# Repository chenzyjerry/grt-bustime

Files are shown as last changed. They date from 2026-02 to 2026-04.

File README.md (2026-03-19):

# grt-bustime

Fetch the next two Grand River Transit (GRT) bus arrival times at a stop using a Raspberry Pi and show the arrival time for the two selected bus routes on 7 segment displays.

This project is not affiliated in any way with Grand River Transit. I just like transit.

Interested in doing this yourself? Read the instructions in ```./docs/Instructions.md```.

## Photos

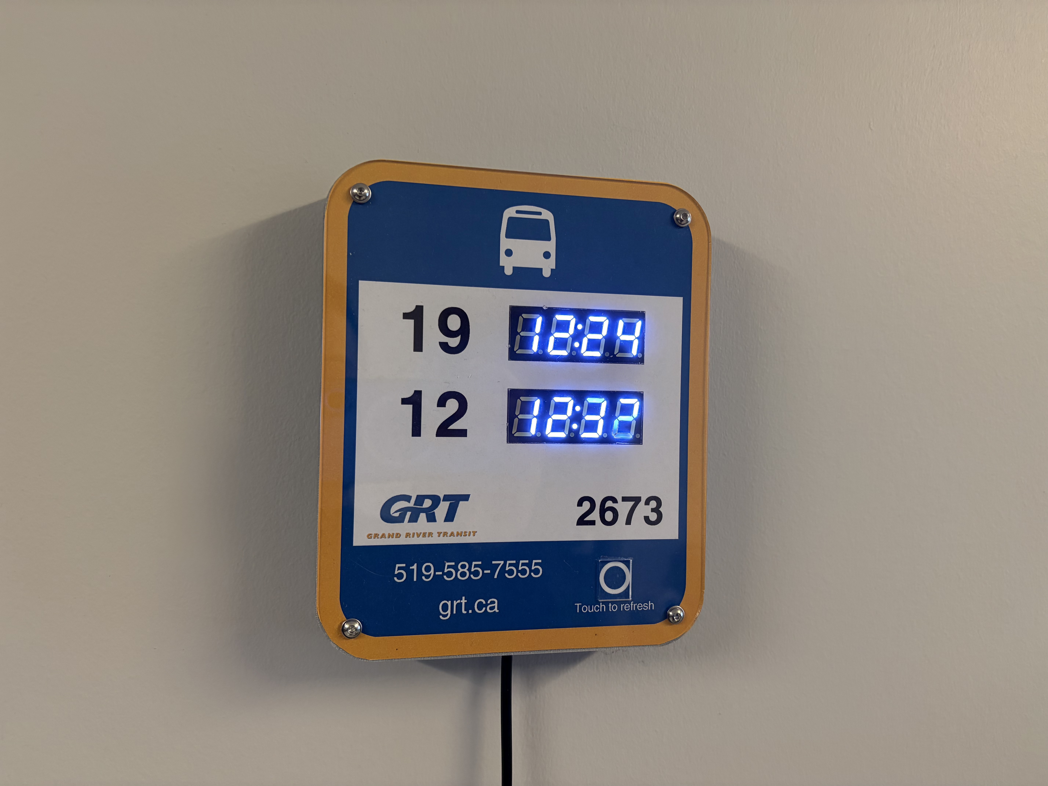
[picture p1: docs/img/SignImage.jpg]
Completed Sign


## Why?

There are two busses at the nearest bus stop to my apartment which go to the University of Waterloo. I would like to know when they will arrive at my stop so I can leave early enough to catch them.

This hardware solution is a fun little project and a satifying way to check the times without having to pull out my phone and look at a transit app. It's also a fantastic way for me to try out writing code using an AI Agent (Copilot).

## Design

### Hardware

The hardware centers around a Pi Zero 2W, two 4-digit 7 segment displays with TM1637 drivers, and a TTP223 capacitive touch module. 

The Pi Zero 2W was chosen for its compact size and low power draw. 

Because all that is being displayed is an arrival time, the 7 segment displays are much easier to implement and cheaper than options like an eInk or OLED display. They also more closely match the digital signage present on GRT bus stops.

A capacitive touch module was chosen over a mehcanical button, as it allows for a cleanly integrated button in the display face.

All the componenets were wired together using JST connectors to allow for easy replacement when the display modules inevitably burn out. A perfboard is used to make the wiring very neat - although it could also be done using just jumper wires.

The 3D printed case cleanly integrates all the components in a thin housing and imitates a bus stop sign. All screws thread into heat inserts to ensure longevity. The case retains the Pi's power cable to prevent accidental unplugging.

The printed paper face decal allows for colourful and detailed decals to be displayed, but makes it also very easy to change out if I were to move to a different city and need to update it for a new transit agency. This decal is proctected by an acrylic faceplate.

### Software

The ```bus_arrival_times.py``` script pulls the latest transit arrival time data from the GRT Realtime API. Unfortunately, GRT provides this in the [General Transit Feed Specification (GTFS)](https://gtfs.org/) format, which produces protobuf files which may be too large for most microcontrolers to handle, necessitating the use of a Pi. The realtime data can be searched to produce a list of the exepcted arrival times of all the busses at a certain stop.

The trip numbers of the live trips are compared with the static feed from the GRT API to determine the route number of each inbound bus. This then allows the script to find the arrival times of the next busses of the configured routes and display them using the [Pi TM1637 library](https://github.com/depklyon/raspberrypi-tm1637).

The static data is pulled every 12 hours and then cached. The realtime trip data is pulled every 3 minutes and the displays are refreshed, unless the capacitive touch sensor is pressed which forces fresh realtime data to be pulled.

## Related Projects
Adafruit has a similar NextBus project using the [NextBus](https://rider.umoiq.com/) interface. Their transit clock works with ESP8266, Adafruit MagTag, and Raspberry Pi: [Adafruit NextBus](https://learn.adafruit.com/personalized-esp8266-transit-clock)

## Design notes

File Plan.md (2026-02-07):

What: GRT bus arrival time display for the next 19 and 12 busses at my closest bus stop (2783). Display will allow me to decide when to leave to catch a bus to class.

Hardware:
- Raspberry Pi Zero V2: Fetches bus arrival times every 3 minutes from [GRT API](https://webapps.regionofwaterloo.ca/api/grt-routes/api/tripupdates) and displays arrival times in (MM:SS) format on two 7-segment displays.
- Two 7-segment displays: Displays next bus arrival times.
- Capacitive button: Allows user to force refresh arrival time.

Software Design:
- Fetch and display time:
	- Fetch bus arrival times every 3 minutes from [GRT API](https://webapps.regionofwaterloo.ca/api/grt-routes/api/tripupdates), as a file in protobuf format
		- If fetching fails, display *FEt Err* on the displays (*FEt* on one display, *Err* on the second)
	- Parse protobuf file, which stores data in the [GTFS](https://gtfs.org/) format, for stop 2783, and record the next arrival times for the 19 and 12 busses.
	- Display this time to each of the 7-segment displays
	- Edge case handling:
		- If next bus is cancelled/my stop will be skipped, display time for the bus after.
		- If next bus is over 1hr away (aka, nighttime service end), display *----*.
- Use interrupts to monitor for capacitive button presses to force fetch and display process

Mechanical Design:
- Pi has a custom perfboard HAT which simplifies all the wiring.
- Pi is mounted near to bottom of case (using standoffs), allowing for power supply to be directly plugged in.
- Front panel is 3 layers: Base layer is a 3D print to which components are mounted, middle layer is a printed graphic, outer layer is a clear piece of acrylic. This sandwich design allows for the graphic layer to be exchanged in case I move and a different stop is nearby, or I move cities and the transit agency changes.
	- 7-segment display and capacitive button are mounted to front panel base layer and connected to HAT via removable JST headers/connectors. This will allow for modules to be easily replaced without having to mess with the soldering on the perfboard.
		- White 7-segment displays have orange gel filter to resemble the official dot-matrix orange signage
	- Middle graphic layer is themed to make it look like official GRT bus stop signage.
		- Blue, white, and gold graphics in Arial Bold or whatever the official font is.
		- Bus route number (12, 19) printed next to each display.
		- Small circled 👆 icon over the capacitive button.
	- Outer acrylic layer sandwiches all layers and screws into case
- Case is rectangular with rounded edges similar to the bus stop signs. Sanded smooth and spray painted silver to imitate official metal signage
- Mounted to wall using 3M 5lb adhesive strip

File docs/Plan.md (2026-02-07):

What: GRT bus arrival time display for the next 19 and 12 busses at my closest bus stop (2783). Display will allow me to decide when to leave to catch a bus to class.

Hardware:
- Raspberry Pi Zero V2: Fetches bus arrival times every 3 minutes from [GRT API](https://webapps.regionofwaterloo.ca/api/grt-routes/api/tripupdates) and displays arrival times in (MM:SS) format on two 7-segment displays.
- Two 7-segment displays: Displays next bus arrival times.
- Capacitive button: Allows user to force refresh arrival time.

Software Design:
- Bus Stop # (2783) and the two bus route numbers (12, 19) stored in plain text in .csv format to allow easy editing without having to touch the code
- Fetch and display time:
	- Fetch bus arrival times every 3 minutes from [GRT API](https://webapps.regionofwaterloo.ca/api/grt-routes/api/tripupdates), as a file in protobuf format
		- If fetching fails, display *FEt Err* on the displays (*FEt* on one display, *Err* on the second)
	- Parse protobuf file, which stores data in the [GTFS](https://gtfs.org/) format, for stop 2783, and record the next arrival times for the 19 and 12 busses.
	- Display this time to each of the 7-segment displays
	- Edge case handling:
		- If next bus is cancelled/my stop will be skipped, display time for the bus after.
		- If next bus is over 1hr away (aka, nighttime service end), display *----*.
- Use interrupts to monitor for capacitive button presses to force fetch and display process

Mechanical Design:
- Pi has a custom perfboard HAT which simplifies all the wiring.
- Pi is mounted near to bottom of case (using standoffs), allowing for power supply to be directly plugged in.
- Front panel is 3 layers: Base layer is a 3D print to which components are mounted, middle layer is a printed graphic, outer layer is a clear piece of acrylic.
	- 7-segment display and capacitive button are mounted to front panel base layer and connected to HAT via removable JST headers/connectors. This will allow for modules to be easily replaced without having to mess with the soldering on the perfboard.
		- White 7-segment displays have orange gel filter to resemble the official dot-matrix orange signage
	- Middle graphic layer is themed to make it look like official GRT bus stop signage.
		- This sandwich design allows for the graphic layer to be exchanged in case I move and a different stop is nearby, or I move cities and the transit agency changes. I would only need to reprint a piece of paper, which I can do even if I live somewhere without access to a 3D printer/other tools.
		- Blue, white, and gold graphics in Arial Bold or whatever the official font is.
		- Bus route number (12, 19) printed next to each display.
		- Small circled 👆 icon over the capacitive button.
	- Outer acrylic layer sandwiches all layers and screws into case
- Case is rectangular with rounded edges similar to the bus stop signs. Sanded smooth and spray painted silver to imitate official metal signage
- Mounted to wall using 3M 5lb adhesive strip

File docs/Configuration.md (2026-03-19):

# Configuration Guide

This document explains how to configure the GRT Bus Time Display system using the `config.txt` file.

## Overview

All settings for the bus arrival time display are now stored in `config.txt` in the `src/` directory. You no longer need to edit Python code to change settings - simply modify `config.txt` and restart the program.

## Configuration File Location

```
src/config.txt
```

## How to Modify Settings

1. Open `src/config.txt` in any text editor
2. Change the values as needed (see below for details)
3. Save the file
4. Restart the program for changes to take effect

## Configuration Options

### API Configuration

**API_URL**
- The endpoint URL for the GRT real-time bus API
- Default: `https://webapps.regionofwaterloo.ca/api/grt-routes/api/tripupdates/1`
- Change this only if GRT updates their API endpoint

**STATIC_GTFS_URL**
- The endpoint URL for the static GTFS data (schedule information)
- Default: `https://webapps.regionofwaterloo.ca/api/grt-routes/api/staticfeeds/1`
- This is used to get destination/direction information (headsigns) for bus trips
- Change this only if GRT updates their API endpoint

**STOP_ID**
- The GRT bus stop ID where you want to monitor arrivals
- Default: `2673`
- To find your stop ID, visit the GRT website or check a transit app

**LOCAL_TZ**
- Your timezone (IANA timezone name)
- Default: `America/Toronto`
- Examples: `America/New_York`, `America/Denver`, `America/Los_Angeles`
- Find your timezone at: https://en.wikipedia.org/wiki/List_of_tz_database_time_zones

### Display 1 Configuration

**DISPLAY1_ROUTE**
- Route number displayed on the first TM1637 display
- Default: `12`
- Example: `12`, `19`, `5`

**DISPLAY1_HEADSIGN**
- Filter arrivals by destination/direction (headsign)
- Leave blank to show all directions for this route
- Example values: `Downtown`, `Fairway Station`, `Waterloo Station`, `University of Waterloo`
- To find available headsigns for your route, run: `python test_directions.py`
- The program will display all available destinations for your configured routes

**DISPLAY1_CLK**
- GPIO pin for the first display's clock signal
- Default: `27`
- Common values: `27`, `17`, `22`

**DISPLAY1_DIO**
- GPIO pin for the first display's data signal
- Default: `17`
- Common values: `17`, `23`, `24`

### Display 2 Configuration

**DISPLAY2_ROUTE**
- Route number displayed on the second TM1637 display
- Default: `19`
- Example: `12`, `19`, `5`

**DISPLAY2_HEADSIGN**
- Filter arrivals by destination/direction (headsign)
- Leave blank to show all directions for this route
- Example values: `Downtown`, `Fairway Station`, `Waterloo Station`, `University of Waterloo`
- To find available headsigns for your route, run: `python test_directions.py`
- The program will display all available destinations for your configured routes

**DISPLAY2_CLK**
- GPIO pin for the second display's clock signal
- Default: `24`
- Common values: `27`, `17`, `22`

**DISPLAY2_DIO**
- GPIO pin for the second display's data signal
- Default: `23`
- Common values: `17`, `23`, `24`

### Capacitive Sensor Configuration

**SENSOR_PIN**
- GPIO pin for the TTP223 capacitive touch sensor
- Default: `4`
- This button triggers a manual refresh of bus arrival times

### Sunset Dimming Configuration

**ENABLE_SUNSET_DIMMING**
- Enable automatic brightness dimming after sunset
- Options: `true` or `false`
- Default: `true`
- Requires the `astral` Python library; if not installed, dimming is disabled

**DAY_BRIGHTNESS**
- Display brightness level during daytime
- Range: `0-7` (0 = dimmest, 7 = brightest)
- Default: `7`

**NIGHT_BRIGHTNESS**
- Display brightness level after sunset
- Range: `0-7` (0 = dimmest, 7 = brightest)
- Default: `2`

### Location Configuration

**LOCATION_LATITUDE**
- Your latitude for sunset calculation
- Default: `43.4516` (Waterloo, ON)
- Example: `43.4516` for Waterloo
- Precision: 4 decimal places is sufficient

**LOCATION_LONGITUDE**
- Your longitude for sunset calculation
- Default: `-80.4925` (Waterloo, ON)
- Example: `-80.4925` for Waterloo
- Note: Western hemisphere is negative

### Refresh Interval

**REFRESH_INTERVAL**
- How often to fetch updated bus arrival times from the API
- Specified in seconds
- Default: `180` (3 minutes)
- Minimum recommended: `60` (1 minute)
- Set higher to reduce network usage, lower for more frequent updates

**STATIC_GTFS_REFRESH_INTERVAL**
- How often to refresh the static GTFS data (trip-to-headsign mapping)
- Specified in seconds
- Default: `43200` (12 hours)
- This data is used to look up destination names (headsigns) for each bus trip
- Common values:
  - `43200` - 12 hours (recommended)
  - `86400` - 24 hours (daily)
  - `21600` - 6 hours (more frequent)
- Lower values: More frequent updates to schedule/destination information, but higher bandwidth
- Higher values: Less frequent updates, lower bandwidth usage
- Start with the default and adjust based on how often route schedules change

## Finding Your Headsigns

The headsign (also called trip_headsign or destination) is the destination name for a bus trip. To discover which headsigns are available for your routes:

1. Ensure your `STOP_ID`, `DISPLAY1_ROUTE`, and `DISPLAY2_ROUTE` are correctly configured
2. Run the test script:
   ```bash
   cd src/
   python test_directions.py
   ```
3. The script will display all upcoming arrivals grouped by route and destination
4. Copy the exact headsign text (e.g., "Downtown", "Fairway Station") into your config file
5. To show all destinations for a route, leave the headsign blank

## Example Configurations

### Two Bus Routes with Specific Destinations

```
API_URL = https://webapps.regionofwaterloo.ca/api/grt-routes/api/tripupdates/1
STATIC_GTFS_URL = https://webapps.regionofwaterloo.ca/api/grt-routes/api/staticfeeds/1
STOP_ID = 2673
LOCAL_TZ = America/Toronto

DISPLAY1_ROUTE = 12
DISPLAY1_HEADSIGN = Fairway Station
DISPLAY1_CLK = 27
DISPLAY1_DIO = 17

DISPLAY2_ROUTE = 19
DISPLAY2_HEADSIGN = University of Waterloo Station
DISPLAY2_CLK = 24
DISPLAY2_DIO = 23

SENSOR_PIN = 4

ENABLE_SUNSET_DIMMING = true
DAY_BRIGHTNESS = 7
NIGHT_BRIGHTNESS = 2

LOCATION_LATITUDE = 43.4516
LOCATION_LONGITUDE = -80.4925

REFRESH_INTERVAL = 180
```

### Two Bus Routes (All Destinations)

Leave `DISPLAY1_HEADSIGN` and `DISPLAY2_HEADSIGN` blank to show arrivals for all destinations:

```
API_URL = https://webapps.regionofwaterloo.ca/api/grt-routes/api/tripupdates/1
STATIC_GTFS_URL = https://webapps.regionofwaterloo.ca/api/grt-routes/api/staticfeeds/1
STOP_ID = 2673
LOCAL_TZ = America/Toronto

DISPLAY1_ROUTE = 12
DISPLAY1_HEADSIGN = 
DISPLAY1_CLK = 27
DISPLAY1_DIO = 17

DISPLAY2_ROUTE = 19
DISPLAY2_HEADSIGN = 
DISPLAY2_CLK = 24
DISPLAY2_DIO = 23

REFRESH_INTERVAL = 180
```

### Testing (No Dimming, Single Route)

```
ENABLE_SUNSET_DIMMING = false
DAY_BRIGHTNESS = 7

DISPLAY1_ROUTE = 12
DISPLAY2_ROUTE = 12

REFRESH_INTERVAL = 60
```

## Troubleshooting

### Configuration File Not Found

If you get an error like "Configuration file not found: /path/to/config.txt":
- Make sure `config.txt` exists in the `src/` directory
- Check file spelling and location
- The file must be named exactly `config.txt` (lowercase)

### Invalid Configuration Values

Common issues:
- **Brightness values**: Must be between 0 and 7
- **GPIO pins**: Must be valid Raspberry Pi GPIO pin numbers
- **Booleans**: Use `true` or `false` (lowercase)
- **Numbers**: Don't use quotes around numeric values
- **Timezone**: Must be a valid IANA timezone name
- **Headsign**: Must match exactly (check spelling, case, and spacing) - run `test_directions.py` to see exact values

### Headsign Not Working

If your filtered headsign shows no arrivals:
- Run `python test_directions.py` to verify the exact headsign text
- Copy the text exactly (including case and spacing)
- Some headsigns may have trailing or leading spaces - the config loader trims these
- If the headsign is not available at your stop, you may need to use a different stop or leave the headsign blank

### Program Doesn't Recognize Changes

Always restart the program after modifying `config.txt`. The configuration is loaded once when the program starts.

## Format Notes

- **Comments** start with `#` and are ignored
- **Empty lines** are ignored
- **Key = Value** format with `=` separator
- **Whitespace** around keys and values is trimmed automatically
- **Boolean values** must be lowercase: `true` or `false`
- **String values** do not need quotes
- **Numeric values** must not have quotes

## Advanced: Adding More Routes

To monitor additional routes beyond the default two displays, you would need to modify the Python code to add additional display objects and parsing logic. The configuration system is designed for the current two-display setup.

## About Headsigns vs Direction IDs

**Why use headsigns instead of direction IDs?**

Bus systems often use "direction IDs" (like 0 or 1) to indicate opposite directions of the same route. However, the GRT (Grand River Transit) system uses more meaningful descriptions called "headsigns" (e.g., "Downtown", "Waterloo Station", "Fairway Station") to indicate where the bus is heading.

Using headsigns is more user-friendly because:
- You can see exactly where each bus is going
- Configuration is more intuitive (e.g., "Downtown" vs "Direction 0")
- The same route can serve multiple destinations at different times

Use `test_directions.py` to explore available headsigns for your routes!

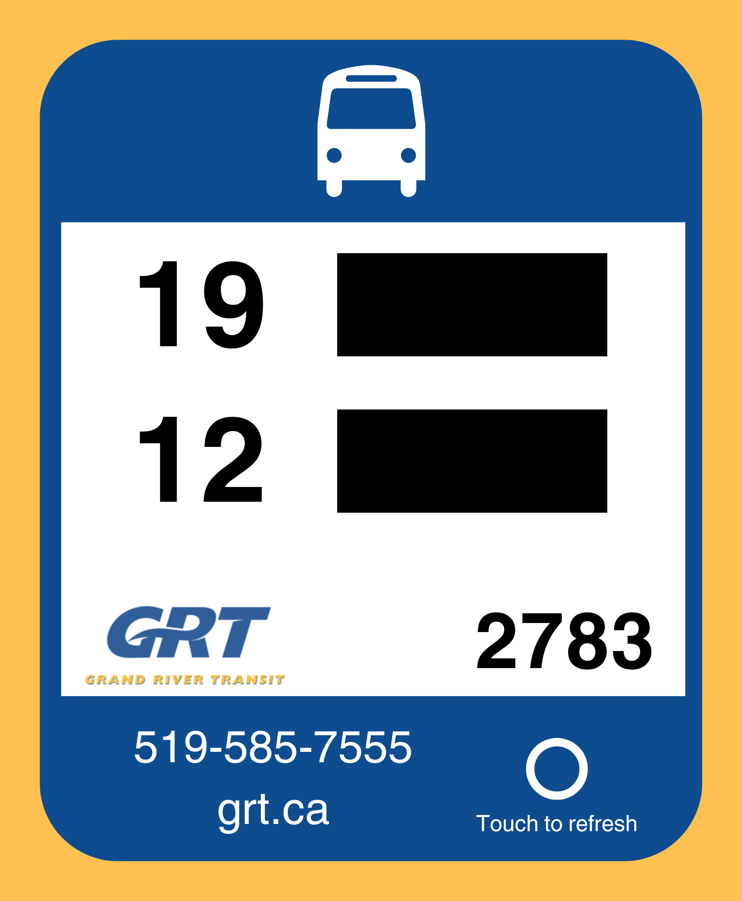
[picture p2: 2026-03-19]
CAD/GRT Bus Time Face Decal.png

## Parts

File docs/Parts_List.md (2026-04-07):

# Parts List

If you want to make your own GRT Bus Arrival Time display, you will need the following parts:

## Raspberry Pi
| Name | Qty | Link | Note |
| ---- | --- | ---- | ---- |
| Raspberry Pi Zero 2W (no headers) | 1 | https://www.pishop.ca/product/raspberry-pi-zero-2-w/ | You can buy the WH version if you don't want to solder the headers yourself. |
| 40 pin male header | 1 | https://www.pishop.ca/product/color-coded-header-for-raspberry-pi/ | Not needed if you bought the WH version. |
| MicroSD Card | 1 | N/A | I used a 64GB Lexar card, but you could definitely get away with ~16GB. |
| Soulbay 5V 3A MicroUSB Power Supply | 1 | https://www.amazon.ca/Raspberry-Supply-SoulBay-Adapter-Android/dp/B07CVH21NC/ |  |

## Wiring HAT
| Name | Qty | Link | Note |
| ---- | --- | ---- | ---- |
| 40 pin short female header | 1 | https://www.pishop.ca/product/gpio-header-for-raspberry-pi-hat-2x20-short-female-header/ |  |
| 7x9cm perfboard | 1 | https://www.aliexpress.com/item/1005005795030364.html |  |
| 4 pin JST XH2.54 10cm cable | 2 | https://www.aliexpress.com/item/1005007460897865.html |  |
| 4 pin JST XH2.54 right angle headers | 2 | https://www.aliexpress.com/item/33008489410.html |  |
| 3 pin JST XH2.54 10cm cable | 1 | https://www.aliexpress.com/item/1005007460897865.html |  |
| 3 pin JST XH2.54 right angle headers | 1 | https://www.aliexpress.com/item/33008489410.html |  |
| 24AWG wires (various colours) | N/A | N/A |  |

## Electrical Components

| Name | Qty | Link | Note |
| ---- | --- | ---- | ---- |
| TM1637 4-digit 7-segment display module (white) | 2 | https://www.aliexpress.com/item/1005001582129952.html |  |
| TTP223 Capacitive Touch Module | 1 | https://www.aliexpress.com/item/1005007894944678.html |  |

## Case

| Name | Qty | Link | Note |
| ---- | --- | ---- | ---- |
| Silver PLA filament | 1kg | https://www.amazon.ca/eSUN-Filament-Dimensional-Accuracy-Printers/dp/B0CS2ZSZ6F/ | Silver or light grey best matches the official signs. |
| M3x4x4.5mm brass heat inserts | 12 | https://www.aliexpress.com/item/1005003582355741.html | M3 thread, 4mm length, 4.5mm OD. |
| M2.5x4x4mm brass heat inserts | 6 | https://www.aliexpress.com/item/1005003582355741.html | M2.5 thread, 4mm length, 4mm OD. |
| M2.5x6x4mm brass heat inserts | 2 | https://www.aliexpress.com/item/1005003582355741.html | M2.5 thread, 6mm length, 4mm OD. |
| M3x16mm button head screw | 4 | N/A |  |
| M3x6mm button head screw | 8 | N/A |  |
| M2.5x6mm button head screw | 8 | N/A |  |
| M3 washer | 4 | N/A |  |
| M3x12mm socket head cap screw | 4 | N/A | Optional, for desk mounting. |
| M3 nut | 4 | N/A | Optional, for desk mounting. |
| 3M 5lb 3M Command Strip | 1 | N/A | For wall mounting. |
| 6x7in 1/16" acrylic sheet | 1 | N/A |  |
| Electrical tape | 1 | N/A |  |

## Tools
| Name | Note |
| ---- | ---- |
| Philips #2 screwdriver |  |
| Philips #00 screwdriver |  |
| Soldering iron |  |
| Soldering iron heat insert tips |  |
| Hot glue gun |  |
| Scissors |  |
| Utility knife | A brand new blade is ideal for easily cutting out the slots in the Face Decal. |

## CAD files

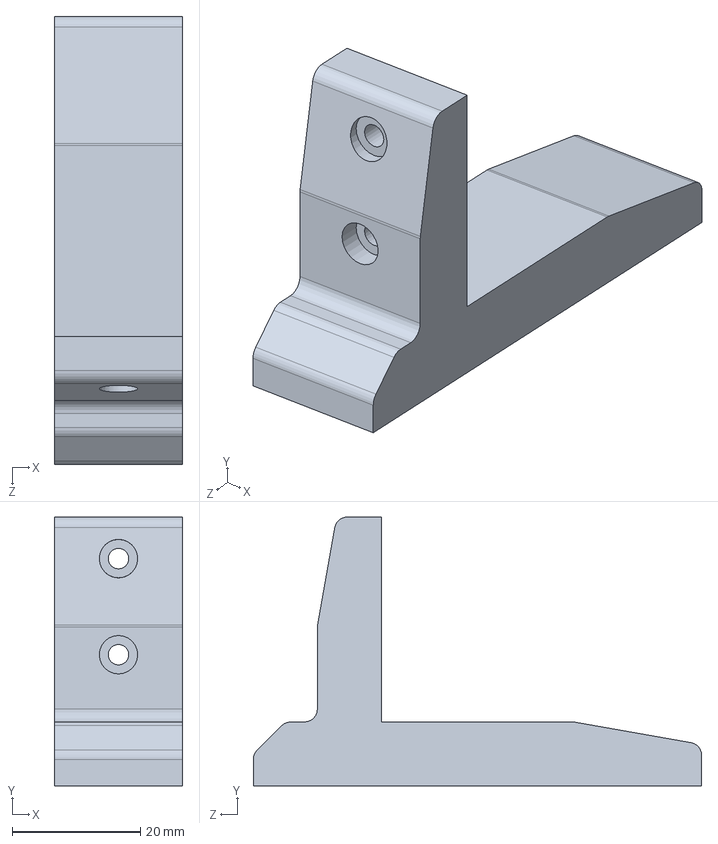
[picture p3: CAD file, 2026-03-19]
CAD/Leg.SLDPRT
20.0 x 42.0 x 70.0 mm

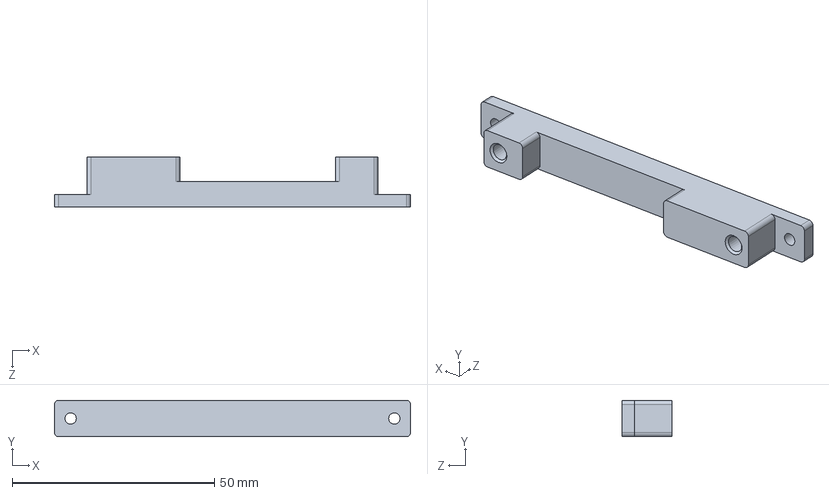
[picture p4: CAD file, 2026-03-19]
CAD/PCB Support Bracket.SLDPRT
88.0 x 9.00 x 12.3 mm

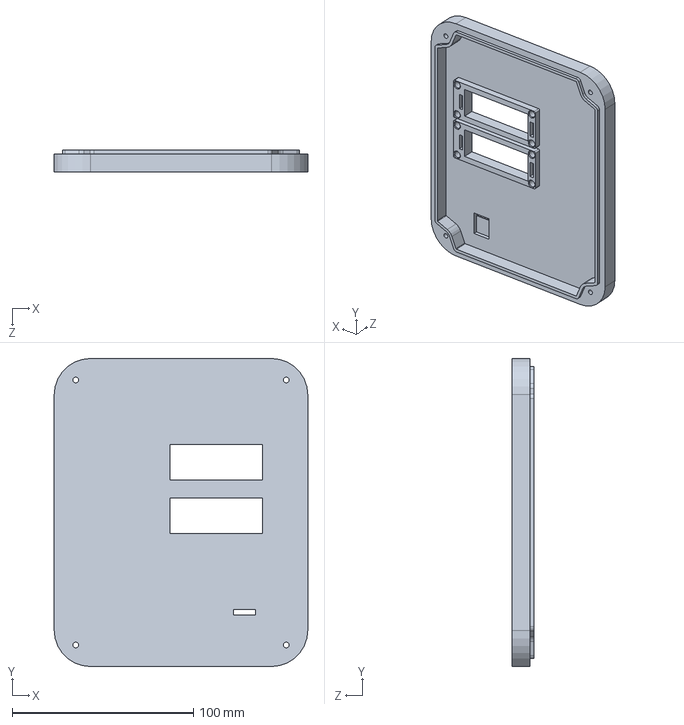
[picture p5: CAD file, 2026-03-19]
CAD/Top Case.SLDPRT
140.0 x 170.0 x 12.0 mm

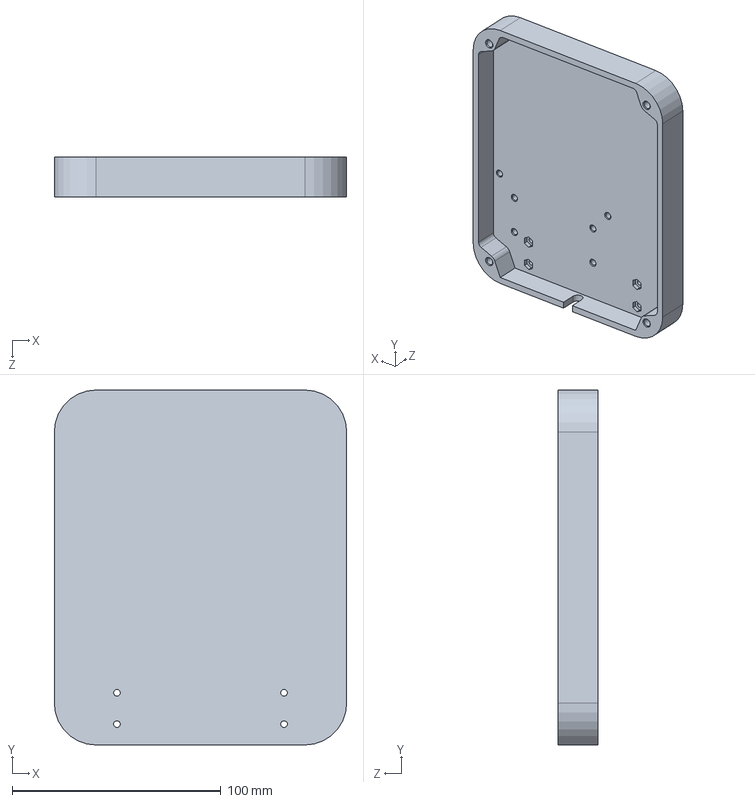
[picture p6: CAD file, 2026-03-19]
CAD/Bottom Case.SLDPRT
140.0 x 170.0 x 19.0 mm

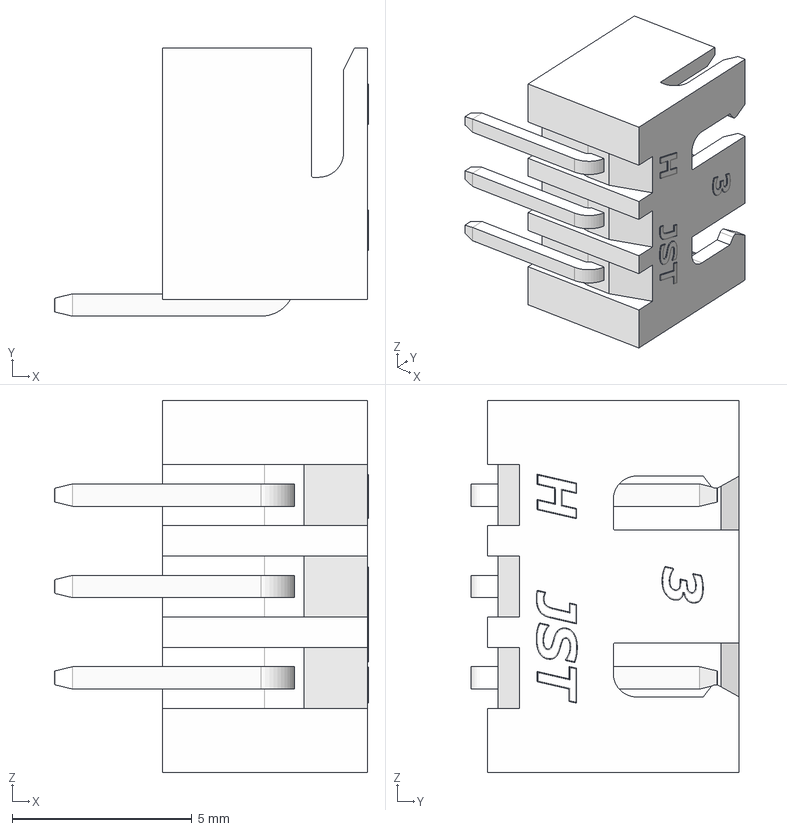
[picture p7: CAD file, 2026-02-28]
CAD/WHITE JST XH 3 PIN CONNECTOR - P 2.54mm - ANGLED.stp
8.73 x 7.46 x 10.3 mm

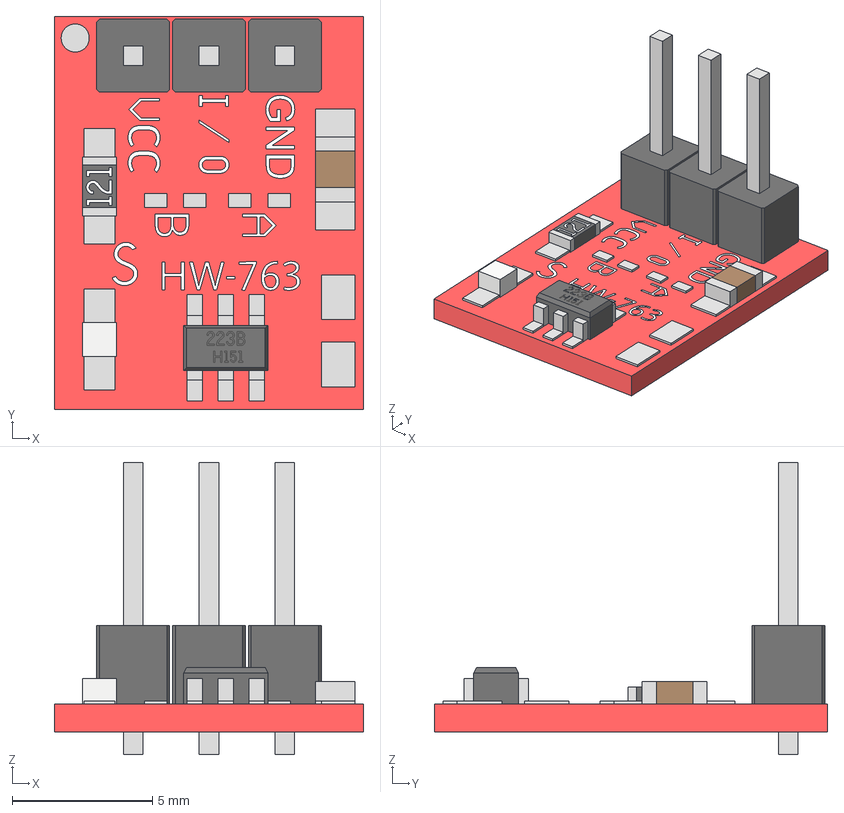
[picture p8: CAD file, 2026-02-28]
CAD/Touch_sensor_HW-763.step
11.0 x 14.0 x 10.4 mm

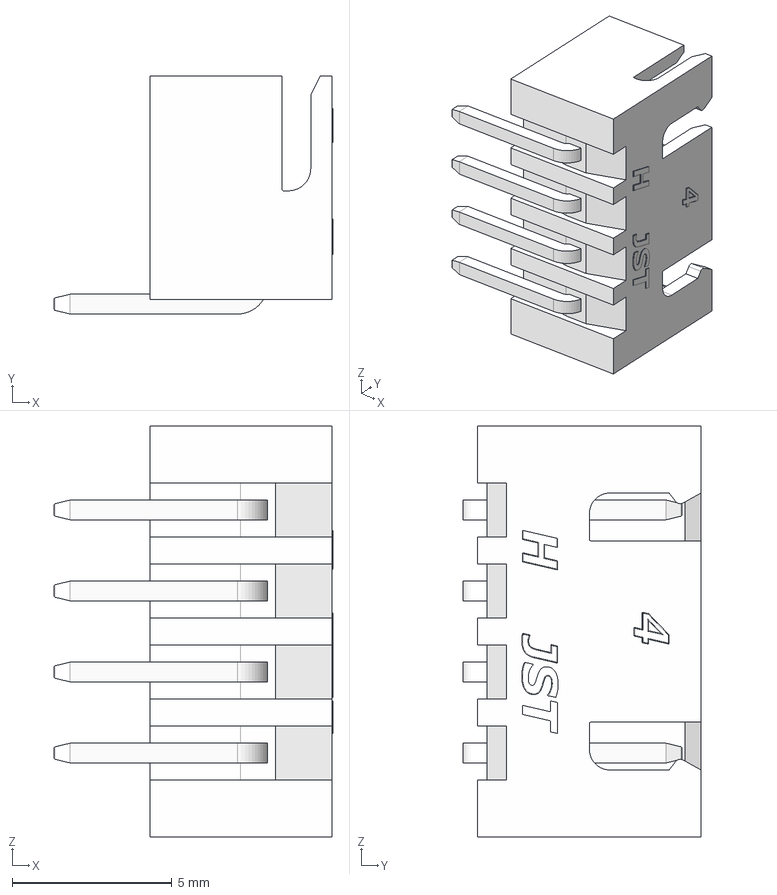
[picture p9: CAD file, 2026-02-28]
CAD/WHITE JST XH 4 PIN CONNECTOR - P 2.54mm - ANGLED.stp
8.73 x 7.46 x 12.9 mm

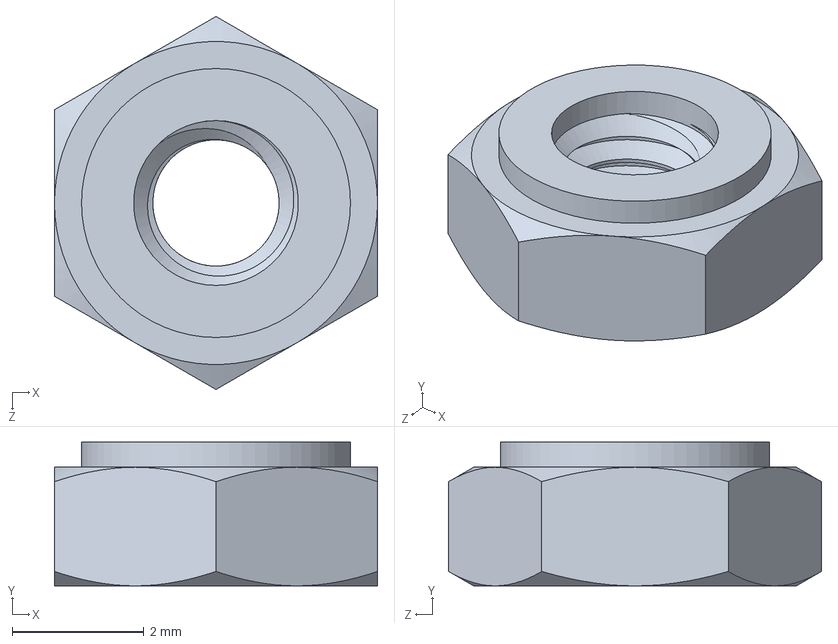
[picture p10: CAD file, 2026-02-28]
CAD/93369A114_Nylon Hex Nut.SLDPRT
4.90 x 2.18 x 5.66 mm

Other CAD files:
CAD/Pi Frame.SLDPRT
CAD/Acrylic Faceplate.SLDPRT
CAD/2x20 Pin Male Header.SLDPRT
CAD/2x20 Pin Female Header.SLDPRT
CAD/Display Frame.SLDPRT
CAD/Perfboard.SLDPRT
CAD/Leg.STL
print_files/Acrylic Faceplate.DWG
print_files/Bottom Case.STL
print_files/Leg.STL
print_files/PCB Support Bracket.STL
print_files/Pi Frame.STL
print_files/Top Case.STL

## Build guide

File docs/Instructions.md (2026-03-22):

# Instructions

So, you want to make your own GRT bus time display. If you do, bonus cool points! The instructions are as follows:

## Assemble Hardware

1. Cut your 7x9cm perfboard lengthwise so you are left with a roughly 2x9cm segment.

2. Solder 40 pin male header onto Raspberry Pi Zero 2W.

2. Solder 40 pin female header onto perfboard.

3. Solder two 4-pin right-angle JST-XH and one 3-pin right-angle JST-XH header onto the perboard. Solder the corresponding 4 pin cables to the display modules, and the 3 pin cable to the touch sensor. I would also recommend adding hot glue to the solder joints for strain relief.

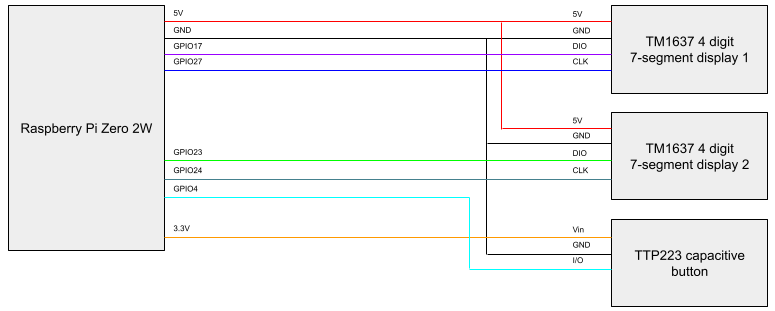
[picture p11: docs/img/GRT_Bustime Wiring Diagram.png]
Wiring Diagram
4. Connect the Pi headers to the JST-XH headers on the perfboard as per the following diagram: 

5. Plug the display and touch modules into the perfboard hat, and the hat into the Pi. It should look similar to the following: Assembled Components

6. You should now be done the electrical components. You can choose to test all the components prior to assembly in the case. For that, skip to the Software Setup section.

## Make the Case

All required files can be found in the ```print_files``` folder.

1. 3D print the Bottom Case, Top Case, PCB Support Bracket, and Pi Frame. If you'd like to make it desk mounted, also print out 2 of the Legs.

2. Laser cut the acrylic sheet as per ```Acrylic Faceplate.DWG```. Units are in mm.

3. Print out ```GRT Bus Time Face Decal.pdf```. Ensure that it prints to the proper scale. Cut out the black boxes for the displays, and use the acrylic faceplate as a guide to cut out the corners and punch the screw holes. Place a small square of transparent tape over the refresh button location.

4. Add the two 6mm M2.5 heat inserts to the PCB support bracket: PCB Support bracket

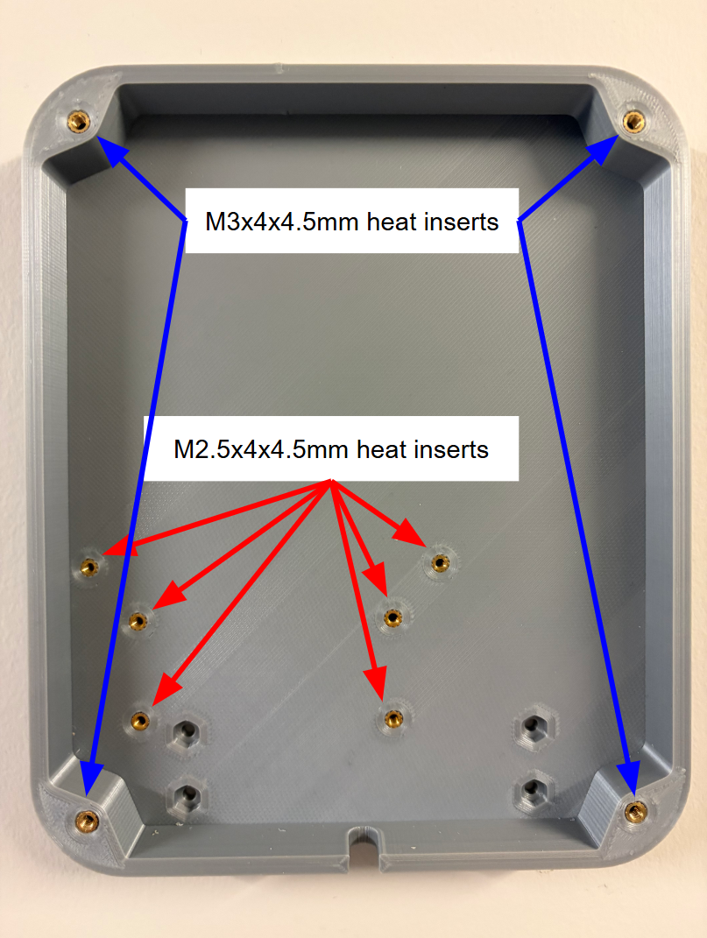
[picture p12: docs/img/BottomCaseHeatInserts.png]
Bottom Case Heat Inserts
5. Add the four M3 heat inserts to the corners of the Bottom Case. Add the six 4mm M2.5 heat inserts as shown below: 

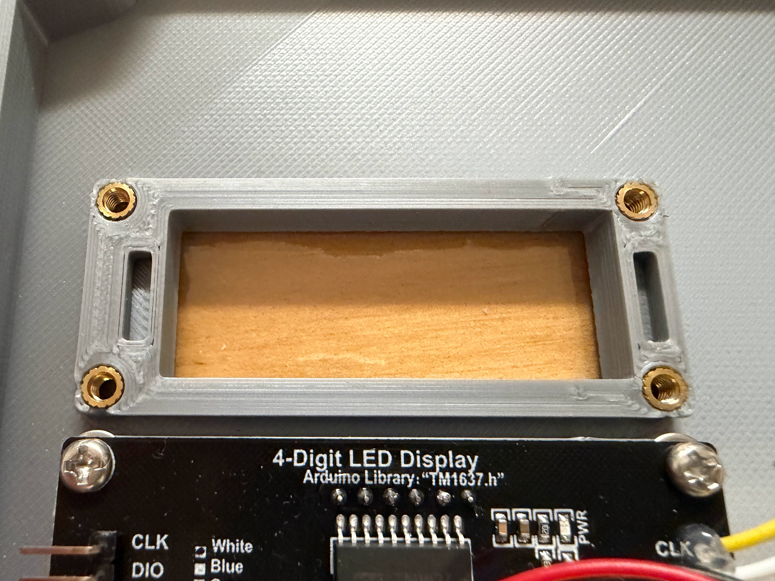
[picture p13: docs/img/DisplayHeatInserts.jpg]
Display Heat Inserts
6. Add four M3 heat inserts to each corner of the display brackets on the inside face of the Top Case: 

> [!NOTE]
> If you want to make it desk mounted, slot the M3 nuts into the hexagonal holes on the Bottom Case. Fasten the legs to the case using the four M3x12 screws from the back of the case.

7. Plug the MicroUSB power supply into the Pi.

> [!WARNING]
> The power supply must be plugged in prior to assembly, as it is not possible to do so once the case is closed.

7. Secure the Pi to the Bottom Case using the four M2.5x6 screws, with the Pi Frame underneath as a spacer: Pi and Power Supply Installed

8. Secure the PCB Support Bracket to the Bottom Case using the two M2.5x6 screws.

9. Plug the perfboard into the Pi. Secure the perfboard to the PCB Support Bracket using the two M2.5x6 screws: Pi and Perfboard

10. Secure the touch sensor to the slot in the Top Case with electrical tape.

11. Secure the display modules to the Top Case using four M3x6 screws per display module: Top Case Components Installed

12. Plug in the display modules and touch sensor prior to closing the case. The bottom display module should be plugged into the leftmost 4-pin JST connector. It should now look like the following: Components Installed

13. Place the Top Case on the Bottom Case. Place the Face Decal on top, and then the acrylic faceplate on top of that. Secure the entire assembly using the four M3x16 screws and washers.

14. If you are wall mounting the bus time display, place a 3M Command Strip on the back of the case.

## Software Setup

### Install the OS

Use the [Raspberry Pi Imager](https://www.raspberrypi.com/software/) to flash an OS on to your SD card. Select the device (Pi Zero 2W), and choose an OS. I used ```Raspberry Pi OS Lite (64-bit) Release 2025-12-04```. Choose a hostname (i.e. pi-bustime) and follow the installation process to select your localisation, username/password, Wi-Fi network, and enable SSH.

### Connect to the Pi

Use SSH to connect to your Pi. You can do this many ways, such as directly through your terminal, or using clients like [PuTTY](https://www.chiark.greenend.org.uk/~sgtatham/putty/) or my preferred client, [Tabby](https://github.com/Eugeny/tabby). Log in using the username and password you used when installing the OS.

### Download the code

Update your package list and install Git:
```
sudo apt update
sudo apt install git -y
```

Make a folder where you want the GRT-Bustime code to live and navigate to it:
```
mkdir grt-bustime
cd grt-bustime
```

Clone the repo:
```
git clone https://github.com/chenzyjerry/grt-bustime.git
```

Run the setup script. This will install all the required libraries:
```
cd src
bash setup.sh
```

### Edit the configuration file

There is a configuration text file which will allow you to set things like display brightness, stop number, route numbers, etc. More information on these settings can be found in ```Configuration.md```. Navigate to the file using 
```
nano config.txt
```

Edit the configuration, and then save your changes with ```Ctrl-O, Enter, Ctrl-X```.

### Run the code

Activate your virtual environment and run the script!
```
source venv/bin/activate
python bus_arrival_times.py
```

You should now be able to see a live status in your terminal on the next busses arriving at your stop. It will pull updated data every 3 minutes. Press ```Ctrl-C``` when you want to quit the program.

### Run on Startup with Crontab

To automatically run the script when your Raspberry Pi starts, you can use crontab:

1. Make the startup script executable:
```
chmod +x ~/grt-bustime/src/run_bustime.sh
```

2. Open the crontab editor:
```
crontab -e
```

3. Add this line to the end of the file:
```
@reboot /home/YOUR_USERNAME/grt-bustime/src/run_bustime.sh
```

Replace `YOUR_USERNAME` with your actual Raspberry Pi username.

4. Save and exit (press `Ctrl-O`, then `Enter`, then `Ctrl-X`)

5. Verify the entry was added:
```
crontab -l
```

The script will now automatically start when your Pi boots up. Output is logged to `~/grt-bustime/src/bustime.log`, which you can check to troubleshoot any issues:
```
cat ~/grt-bustime/src/bustime.log
```

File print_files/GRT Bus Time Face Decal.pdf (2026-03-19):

Touch to refresh

19
12

2673

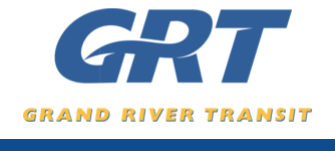
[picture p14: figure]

519-585-7555
grt.ca

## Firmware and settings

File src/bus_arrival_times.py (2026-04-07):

#!/usr/bin/env python3
"""
Fetch the next two bus arrival times for a GRT stop.
Uses the GTFS Realtime API provided by Region of Waterloo.
Direction information is obtained from the static GTFS data.
"""

import requests
from datetime import datetime, timezone, time as datetime_time
from google.transit import gtfs_realtime_pb2
import urllib3
import ssl
from requests.adapters import HTTPAdapter
from urllib3.util.ssl_ import create_urllib3_context
import time
import sys
import os
from zoneinfo import ZoneInfo
from pathlib import Path
import csv
import zipfile
import io
try:
    from astral import Observer
    from astral.sun import sun
    ASTRAL_AVAILABLE = True
except ImportError:
    ASTRAL_AVAILABLE = False
    print("Warning: astral library not found. Sunset dimming disabled.")
try:
    from tm1637 import TM1637
    TM1637_AVAILABLE = True
except ImportError:
    TM1637_AVAILABLE = False
    print("Warning: raspberrypi-tm1637 library not found. Display functionality disabled.")

try:
    import RPi.GPIO as GPIO
    GPIO_AVAILABLE = True
except ImportError:
    GPIO_AVAILABLE = False
    print("Warning: RPi.GPIO library not found. Capacitive sensor functionality disabled.")

# Disable SSL warnings
urllib3.disable_warnings(urllib3.exceptions.InsecureRequestWarning)


def load_config():
    """Load configuration from config.txt file.
    Returns a dictionary with all configuration values.
    Raises FileNotFoundError if config.txt doesn't exist.
    """
    config_path = Path(__file__).parent / "config.txt"
    
    if not config_path.exists():
        raise FileNotFoundError(f"Configuration file not found: {config_path}")
    
    config = {}
    
    with open(config_path, 'r') as f:
        for line in f:
            # Skip empty lines and comments
            line = line.strip()
            if not line or line.startswith('#'):
                continue
            
            # Parse key = value pairs
            if '=' in line:
                key, value = line.split('=', 1)
                key = key.strip()
                value = value.strip()
                
                # Convert string values to appropriate types
                if value.lower() == 'true':
                    config[key] = True
                elif value.lower() == 'false':
                    config[key] = False
                else:
                    # Try to convert to number, otherwise keep as string
                    try:
                        if '.' in value:
                            config[key] = float(value)
                        else:
                            config[key] = int(value)
                    except ValueError:
                        config[key] = value
    
    return config


# Load configuration from file
try:
    CONFIG = load_config()
except FileNotFoundError as e:
    print(f"Error: {e}")
    print("Please create a config.txt file in the src directory.")
    sys.exit(1)

# Extract configuration values
API_URL = CONFIG.get("API_URL", "https://webapps.regionofwaterloo.ca/api/grt-routes/api/tripupdates/1")
STATIC_GTFS_URL = CONFIG.get("STATIC_GTFS_URL", "https://webapps.regionofwaterloo.ca/api/grt-routes/api/staticfeeds/1")
STOP_ID = str(CONFIG.get("STOP_ID", "2783"))
LOCAL_TZ = ZoneInfo(CONFIG.get("LOCAL_TZ", "America/Toronto"))

# TM1637 Display Configuration
DISPLAY1_ROUTE = str(CONFIG.get("DISPLAY1_ROUTE", "12"))
DISPLAY1_HEADSIGN = CONFIG.get("DISPLAY1_HEADSIGN", "")
DISPLAY1_CLK = int(CONFIG.get("DISPLAY1_CLK", 27))
DISPLAY1_DIO = int(CONFIG.get("DISPLAY1_DIO", 17))

DISPLAY2_ROUTE = str(CONFIG.get("DISPLAY2_ROUTE", "19"))
DISPLAY2_HEADSIGN = CONFIG.get("DISPLAY2_HEADSIGN", "")
DISPLAY2_CLK = int(CONFIG.get("DISPLAY2_CLK", 24))
DISPLAY2_DIO = int(CONFIG.get("DISPLAY2_DIO", 23))

# Capacitive Sensor Configuration
SENSOR_PIN = int(CONFIG.get("SENSOR_PIN", 4))

# Sunset Dimming Configuration
ENABLE_SUNSET_DIMMING = CONFIG.get("ENABLE_SUNSET_DIMMING", True)
DAY_BRIGHTNESS = int(CONFIG.get("DAY_BRIGHTNESS", 7))
NIGHT_BRIGHTNESS = int(CONFIG.get("NIGHT_BRIGHTNESS", 2))

# Location for sunset calculation
LOCATION_LATITUDE = float(CONFIG.get("LOCATION_LATITUDE", 43.4516))
LOCATION_LONGITUDE = float(CONFIG.get("LOCATION_LONGITUDE", -80.4925))

# Refresh interval in seconds
REFRESH_INTERVAL = int(CONFIG.get("REFRESH_INTERVAL", 180))

# Static GTFS refresh interval in seconds (default 12 hours)
STATIC_GTFS_REFRESH_INTERVAL = int(CONFIG.get("STATIC_GTFS_REFRESH_INTERVAL", 43200))

# Store headsigns for filtering (empty string means accept all headsigns)
_display1_headsign = DISPLAY1_HEADSIGN.strip() if DISPLAY1_HEADSIGN else ""
_display2_headsign = DISPLAY2_HEADSIGN.strip() if DISPLAY2_HEADSIGN else ""

# Map routes to their desired headsigns (empty string means accept all headsigns)
ROUTE_HEADSIGNS = {
    DISPLAY1_ROUTE: _display1_headsign,
    DISPLAY2_ROUTE: _display2_headsign,
}

# Routes set for filtering (created once to avoid recreation on every fetch)
DESIRED_ROUTES = {DISPLAY1_ROUTE, DISPLAY2_ROUTE}

# Observer for sun calculations (cached to avoid recreation)
_OBSERVER = None
if ASTRAL_AVAILABLE and ENABLE_SUNSET_DIMMING:
    _OBSERVER = Observer(latitude=LOCATION_LATITUDE, longitude=LOCATION_LONGITUDE, elevation=0)

# HTTP session for API calls (reused across fetches)
_API_SESSION = None
_API_SESSION_FAILURE_COUNT = 0  # Track consecutive failures to reset session

# Log loaded configuration on startup
print("[INFO] Configuration loaded from config.txt:")
print(f"[INFO]   Stop ID: {STOP_ID}")
print(f"[INFO]   Route 1: {DISPLAY1_ROUTE}", end="")
if _display1_headsign:
    print(f" (headsign: {_display1_headsign})", end="")
print(f" (GPIO {DISPLAY1_CLK}/{DISPLAY1_DIO})")
print(f"[INFO]   Route 2: {DISPLAY2_ROUTE}", end="")
if _display2_headsign:
    print(f" (headsign: {_display2_headsign})", end="")
print(f" (GPIO {DISPLAY2_CLK}/{DISPLAY2_DIO})")
print(f"[INFO]   Refresh interval: {REFRESH_INTERVAL} seconds")
if ENABLE_SUNSET_DIMMING:
    print(f"[INFO]   Sunset dimming: enabled (day: {DAY_BRIGHTNESS}, night: {NIGHT_BRIGHTNESS})")
else:
    print(f"[INFO]   Sunset dimming: disabled")

def get_sunset_time(date=None):
    """Calculate sunset time for the location.
    Returns datetime object in LOCAL_TZ, or None if calculation fails.
    Uses cached observer instance.
    """
    if not ASTRAL_AVAILABLE or not ENABLE_SUNSET_DIMMING or _OBSERVER is None:
        return None
    
    try:
        if date is None:
            date = datetime.now(LOCAL_TZ).date()
        else:
            date = date.date() if isinstance(date, datetime) else date
        
        sun_times = sun(_OBSERVER, date=date, tzinfo=LOCAL_TZ)
        return sun_times['sunset']
    except Exception as e:
        print(f"[ERROR] Failed to calculate sunset time: {e}")
        return None


def get_sunrise_time(date=None):
    """Calculate sunrise time for the location.
    Returns datetime object in LOCAL_TZ, or None if calculation fails.
    Uses cached observer instance.
    """
    if not ASTRAL_AVAILABLE or not ENABLE_SUNSET_DIMMING or _OBSERVER is None:
        return None
    
    try:
        if date is None:
            date = datetime.now(LOCAL_TZ).date()
        else:
            date = date.date() if isinstance(date, datetime) else date
        
        sun_times = sun(_OBSERVER, date=date, tzinfo=LOCAL_TZ)
        return sun_times['sunrise']
    except Exception as e:
        print(f"[ERROR] Failed to calculate sunrise time: {e}")
        return None


def load_static_gtfs_data():
    """
    Load and cache static GTFS data to build a mapping of trip_id to headsign.
    This is used to filter realtime arrivals by destination/direction.
    Returns a dictionary mapping trip_id to headsign.
    """
    trip_to_headsign = {}
    
    try:
        print("[INFO] Loading static GTFS data for headsign mapping...")
        session = requests.Session()
        session.mount("https://", DH_KeyAdapter())
        
        headers = {
            'User-Agent': 'Mozilla/5.0 (Windows NT 10.0; Win64; x64) AppleWebKit/537.36'
        }
        
        # Download the static GTFS zip file
        response = session.get(STATIC_GTFS_URL, headers=headers, timeout=30)
        response.raise_for_status()
        
        # Extract and parse the trips.txt file
        with zipfile.ZipFile(io.BytesIO(response.content)) as zip_file:
            # Read trips.txt to get trip_id -> headsign mapping
            with zip_file.open('trips.txt') as f:
                reader = csv.DictReader(io.TextIOWrapper(f, encoding='utf-8'))
                for row in reader:
                    trip_id = row.get('trip_id')
                    headsign = row.get('trip_headsign', '')
                    if trip_id:
                        trip_to_headsign[trip_id] = headsign
        
        print(f"[INFO] Loaded {len(trip_to_headsign)} trip-headsign mappings from static GTFS data.")
        return trip_to_headsign
    
    except Exception as e:
        print(f"[ERROR] Failed to load static GTFS data: {e}")
        print("[WARNING] Headsign filtering will be disabled.")
        return {}


# Global cache for trip-to-headsign mapping
_TRIP_TO_HEADSIGN = None
_TRIP_TO_HEADSIGN_TIMESTAMP = None

def get_trip_headsign(trip_id):
    """
    Get the headsign for a given trip_id using cached static GTFS data.
    Returns the headsign (as string) or empty string if not found.
    Loads the data on first call and refreshes if cache has expired.
    """
    global _TRIP_TO_HEADSIGN, _TRIP_TO_HEADSIGN_TIMESTAMP
    
    current_time = time.time()
    
    # Load or refresh if cache is empty or has expired
    if _TRIP_TO_HEADSIGN is None or (current_time - _TRIP_TO_HEADSIGN_TIMESTAMP) > STATIC_GTFS_REFRESH_INTERVAL:
        _TRIP_TO_HEADSIGN = load_static_gtfs_data()
        _TRIP_TO_HEADSIGN_TIMESTAMP = current_time
    
    return _TRIP_TO_HEADSIGN.get(trip_id, "")


class DH_KeyAdapter(HTTPAdapter):
    """Custom adapter to allow weak DH keys for older servers"""
    def init_poolmanager(self, *args, **kwargs):
        ctx = create_urllib3_context()
        ctx.check_hostname = False
        ctx.verify_mode = ssl.CERT_NONE
        ctx.set_ciphers('DEFAULT@SECLEVEL=1')
        kwargs['ssl_context'] = ctx
        return super().init_poolmanager(*args, **kwargs)


def get_api_session():
    """Get or create the API session (reused across calls).
    Session is automatically reset if multiple consecutive failures occur."""
    global _API_SESSION, _API_SESSION_FAILURE_COUNT
    
    # Reset session after 3 consecutive failures to try fresh connection
    if _API_SESSION_FAILURE_COUNT >= 3:
        print(f"[WARNING] Session had {_API_SESSION_FAILURE_COUNT} consecutive failures. Resetting connection...")
        if _API_SESSION is not None:
            try:
                _API_SESSION.close()
            except:
                pass
        _API_SESSION = None
        _API_SESSION_FAILURE_COUNT = 0
    
    if _API_SESSION is None:
        _API_SESSION = requests.Session()
        _API_SESSION.mount("https://", DH_KeyAdapter())
    return _API_SESSION


class CapacitiveSensorManager:
    """Manages TTP223 capacitive sensor for refresh trigger"""
    def __init__(self, callback=None, debug=False):
        self.available = GPIO_AVAILABLE
        self.callback = callback
        self.debug = debug
        self.last_state = 0
        self.state_change_count = 0
        
        if self.available:
            try:
                # Try to set GPIO mode, but don't fail if already set
                try:
                    GPIO.setmode(GPIO.BCM)
                except RuntimeError:
                    # GPIO mode already set, this is fine
                    pass
                
                GPIO.setup(SENSOR_PIN, GPIO.IN)
                
                # Try to remove any existing event detection on this pin first
                try:
                    GPIO.remove_event_detect(SENSOR_PIN)
                except RuntimeError:
                    pass  # No existing event, that's fine
                
                # Read initial state
                self.last_state = GPIO.input(SENSOR_PIN)
                
                # Use polling instead of event detection to avoid conflicts
                print(f"[INFO] Capacitive sensor initialized on pin {SENSOR_PIN} (polling mode).")
                print(f"[INFO] Initial sensor state: {self.last_state}")
            except Exception as e:
                print(f"[ERROR] Failed to initialize capacitive sensor: {e}")
                import traceback
                traceback.print_exc()
                self.available = False
    
    def check_sensor(self):
        """Poll the sensor and trigger callback if pressed (rising edge detected)"""
        if not self.available:
            return
        
        try:
            current_state = GPIO.input(SENSOR_PIN)
            
            # Log state changes in debug mode
            if self.debug and current_state != self.last_state:
                self.state_change_count += 1
                print(f"[DEBUG] Sensor state change #{self.state_change_count}: {self.last_state} -> {current_state}")
            
            # Detect rising edge (0 -> 1) - sensor goes HIGH when touched
            if current_state == 1 and self.last_state == 0:
                print("\n[INFO] Refresh button pressed!")
                if self.callback:
                    self.callback()
            
            # Also detect falling edge (1 -> 0) in case sensor is active-low
            elif current_state == 0 and self.last_state == 1 and self.debug:
                print("[DEBUG] Sensor falling edge detected (active-low test)")
            
            self.last_state = current_state
        except Exception as e:
            print(f"[ERROR] Error reading capacitive sensor: {e}")
            self.available = False
    
    def cleanup(self):
        """Clean up GPIO resources"""
        if self.available:
            try:
                # Don't call GPIO.cleanup() here as it conflicts with TM1637
                # Just let the system clean up when the program exits
                pass
            except Exception as e:
                print(f"[ERROR] Error cleaning up GPIO: {e}")

class TM1637DisplayManager:
    """Manages two TM1637 4-digit 7-segment displays"""
    def __init__(self):
        self.display1 = None
        self.display2 = None
        self.available = TM1637_AVAILABLE
        self.current_brightness = DAY_BRIGHTNESS
        print(f"[INFO] TM1637_AVAILABLE: {TM1637_AVAILABLE}")
        
        if self.available:
            try:
                self.display1 = TM1637(clk=DISPLAY1_CLK, dio=DISPLAY1_DIO)
                self.display2 = TM1637(clk=DISPLAY2_CLK, dio=DISPLAY2_DIO)
                self.display1.brightness(DAY_BRIGHTNESS)  # 0-7 brightness levels
                self.display2.brightness(DAY_BRIGHTNESS)
                print("[INFO] TM1637 displays initialized on pins (CLK/DIO): ({}/{}), ({}/{}).".format(
                    DISPLAY1_CLK, DISPLAY1_DIO, DISPLAY2_CLK, DISPLAY2_DIO))
                if ENABLE_SUNSET_DIMMING and ASTRAL_AVAILABLE:
                    sunset = get_sunset_time()
                    if sunset:
                        print(f"[INFO] Sunset dimming enabled. Sunset time: {sunset.strftime('%H:%M')} (day brightness: {DAY_BRIGHTNESS}, night brightness: {NIGHT_BRIGHTNESS})")
            except Exception as e:
                print(f"[ERROR] Failed to initialize displays: {e}")
                self.available = False
    
    def update_brightness_for_time(self):
        """Update display brightness based on current time relative to sunset.
        Returns True if brightness was changed, False otherwise.
        """
        print(f"[DEBUG] update_brightness_for_time called: available={self.available}, ENABLE_SUNSET_DIMMING={ENABLE_SUNSET_DIMMING}, ASTRAL_AVAILABLE={ASTRAL_AVAILABLE}")
        if not self.available or not ENABLE_SUNSET_DIMMING or not ASTRAL_AVAILABLE:
            print(f"[DEBUG] Skipping brightness update (available={self.available}, dimming_enabled={ENABLE_SUNSET_DIMMING}, astral_available={ASTRAL_AVAILABLE})")
            return False
        
        try:
            now = datetime.now(LOCAL_TZ)
            
            # Get sunrise and sunset for today
            sunrise_today = get_sunrise_time(now)
            sunset_today = get_sunset_time(now)
            
            if sunrise_today is None or sunset_today is None:
                print(f"[DEBUG] Sunrise/sunset calculation returned None")
                return False
            
            # Determine if it's night or day
            is_night = False
            
            if now >= sunset_today:
                # After today's sunset - it's night
                is_night = True
                print(f"[DEBUG] After sunset: {sunset_today.strftime('%H:%M:%S')}")
            elif now < sunrise_today:
                # Before today's sunrise - still night from yesterday
                is_night = True
                print(f"[DEBUG] Before sunrise: {sunrise_today.strftime('%H:%M:%S')}, still night from yesterday")
            else:
                # Between sunrise and sunset - it's day
                print(f"[DEBUG] Between sunrise ({sunrise_today.strftime('%H:%M:%S')}) and sunset ({sunset_today.strftime('%H:%M:%S')})")
            
            # Determine target brightness
            target_brightness = NIGHT_BRIGHTNESS if is_night else DAY_BRIGHTNESS
            
            # Debug output
            print(f"[DEBUG] Brightness check: now={now.strftime('%H:%M:%S')}, is_night={is_night}, target={target_brightness}, current={self.current_brightness}")
            
            # Update brightness if it changed
            if target_brightness != self.current_brightness:
                self.current_brightness = target_brightness
                self.display1.brightness(target_brightness)
                self.display2.brightness(target_brightness)
                time_str = now.strftime('%H:%M:%S')
                state = "night" if target_brightness == NIGHT_BRIGHTNESS else "day"
                print(f"[INFO] [{time_str}] Brightness updated to {target_brightness} ({state} mode)")
                return True
            return False
        except Exception as e:
            print(f"[ERROR] Failed to update brightness: {e}")
            import traceback
            traceback.print_exc()
            return False
    
    def show_arrivals(self, arrival1=None, arrival2=None):
        """Display arrival times on the two displays.
        arrival1, arrival2: arrival dicts with 'time' and 'route_id' keys, or None if no bus.
        """
        if not self.available:
            return
        
        try:
            # Display 1: Show first arrival time as HHMM
            if arrival1:
                local_time = arrival1["time"].astimezone(LOCAL_TZ)
                time_obj = local_time.time()
                self.display1.time(time_obj, colon=True, leading_zero=False)
            else:
                self.display1.show("----")
            
            # Display 2: Show second arrival time as HHMM
            if arrival2:
                local_time = arrival2["time"].astimezone(LOCAL_TZ)
                time_obj = local_time.time()
                self.display2.time(time_obj, colon=True, leading_zero=False)
            else:
                self.display2.show("----")
        except Exception as e:
            print(f"[ERROR] Failed to update displays: {e}")
            import traceback
            traceback.print_exc()
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

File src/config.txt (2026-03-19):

# GRT Bus Time Display Configuration File
# This file contains all configurable settings for the bus arrival time display system.
# Modify values below and save the file, then restart the program.

# ==================== API Configuration ====================
# API endpoint to fetch real-time bus data
API_URL = https://webapps.regionofwaterloo.ca/api/grt-routes/api/tripupdates/1

# URL for static GTFS data (used to get headsigns/destinations for trips)
STATIC_GTFS_URL = https://webapps.regionofwaterloo.ca/api/grt-routes/api/staticfeeds/1

# Bus stop ID where you want to monitor arrivals
STOP_ID = 2673

# Timezone (IANA timezone name)
LOCAL_TZ = America/Toronto

# ==================== Display 1 Configuration ====================
# Route number to display on display 1
DISPLAY1_ROUTE = 12

# Headsign (destination/direction) for display 1 route (leave empty to show all destinations)
# This filters arrivals by their destination name (e.g., "Downtown", "Waterloo").
# Run test_directions.py to see available headsigns for your routes.
DISPLAY1_HEADSIGN = Fairway Station

# GPIO pin for display 1 clock signal
DISPLAY1_CLK = 27

# GPIO pin for display 1 data signal
DISPLAY1_DIO = 17

# ==================== Display 2 Configuration ====================
# Route number to display on display 2
DISPLAY2_ROUTE = 19

# Headsign (destination/direction) for display 2 route (leave empty to show all destinations)
# This filters arrivals by their destination name (e.g., "Downtown", "Waterloo").
# Run test_directions.py to see available headsigns for your routes.
DISPLAY2_HEADSIGN =  University of Waterloo Station

# GPIO pin for display 2 clock signal
DISPLAY2_CLK = 24

# GPIO pin for display 2 data signal
DISPLAY2_DIO = 23

# ==================== Capacitive Sensor Configuration ====================
# GPIO pin for the TTP223 capacitive touch sensor
SENSOR_PIN = 4

# ==================== Sunset Dimming Configuration ====================
# Enable automatic brightness dimming after sunset (true/false)
ENABLE_SUNSET_DIMMING = true

# Display brightness during day (0-7, where 7 is brightest)
DAY_BRIGHTNESS = 7

# Display brightness after sunset (0-7, where 7 is brightest)
NIGHT_BRIGHTNESS = 0

# ==================== Location Configuration ====================
# Latitude of your location (for sunset calculation)
LOCATION_LATITUDE = 43.4516

# Longitude of your location (for sunset calculation)
LOCATION_LONGITUDE = -80.4925

# ==================== Refresh Interval ====================
# How often to refresh bus arrival times (in seconds)
REFRESH_INTERVAL = 180

# How often to refresh static GTFS data for trip-to-headsign mapping (in seconds)
# Default: 43200 (12 hours)
# This controls how frequently the program downloads updated schedule/destination info
# Set to 86400 for daily refresh, or lower for more frequent updates
STATIC_GTFS_REFRESH_INTERVAL = 43200

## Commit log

2026-02-07 Add setup script for GRT Bus Time on Raspberry Pi
2026-02-07 Fix import statement and update requirements for GTFS Realtime bindings
    [bus_arrival_times.py]
2026-02-08 Enhance fetch_bus_arrivals function to use UTC-aware datetime for future arrivals filtering and improve debug output for arrival times
2026-02-08 Enhance fetch_bus_arrivals function to display arrival times in local timezone and improve debug output for current time
2026-02-13 Refactor TM1637 import and update requirements to specify raspberrypi-tm1637
2026-02-13 Fix TM1637 initialization parameter names to match updated library requirements
    [bus_arrival_times.py]
2026-02-13 Fix DISPLAY2_CLK configuration for TM1637 display
    [bus_arrival_times.py]
2026-02-13 Add fallback methods for TM1637 display in case of errors
    [bus_arrival_times.py]
2026-02-13 Enhance TM1637 display methods with debugging output and error handling
    [bus_arrival_times.py]
2026-02-13 Refactor TM1637 display methods to use segment conversion and improve error handling
    [bus_arrival_times.py]
2026-02-13 Add diagnostic test script for TM1637 displays to check GPIO and power
2026-02-13 Update GPIO pin assignments for TM1637 displays in diagnostic test
2026-02-13 Update TM1637 display GPIO pin assignments for consistency
2026-02-13 Fix time format in test sequence for TM1637 displays
    [test_display.py]
2026-02-13 Add capacitive sensor support and enhance bus arrival fetching logic
2026-02-13 Improve GPIO setup in CapacitiveSensorManager to handle already set mode gracefully
2026-02-13 Refactor CapacitiveSensorManager to use polling for sensor detection and improve initialization process
2026-02-13 Enhance CapacitiveSensorManager with debug mode and state change logging; add test script for TTP223 sensor
2026-02-13 Enhance main loop to poll sensor frequently during wait time for bus arrival data
2026-02-13 Recalculate current time in main loop for accurate countdown to bus arrivals
2026-02-13 Filter bus arrivals to include only desired routes and update debug output for future arrivals
2026-02-27 Update TM1637 display configuration with correct CLK and DIO pin assignments
    [bus_arrival_times.py]
2026-02-28 Created CAD for casing
    [93369A114_Nylon Hex Nut.SLDPRT, Bottom Case.SLDPRT, PCB Support Bracket.SLDPRT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]
2026-03-01 Finished CAD
    [2x20 Pin Female Header.SLDPRT, 2x20 Pin Male Header.SLDPRT, Acrylic Faceplate.SLDPRT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]
2026-03-10 Add configuration loading from config.txt for bus arrival display settings
    [config.txt]
2026-03-11 Update night brightness setting for sunset dimming feature
    [config.txt]
2026-03-11 Update night brightness setting to disable dimming after sunset
    [config.txt]
2026-03-11 Fix display pin assignments and enhance brightness testing functionality
    [test_display.py]
2026-03-11 Track last brightness check time to optimize updates based on sunset
2026-03-11 Add debug logging to brightness update logic for better traceability
2026-03-11 Add direction ID configuration for displays and update setup instructions
    [config.txt]
2026-03-11 Add static GTFS URL configuration and update direction ID comments for displays
    [config.txt]
2026-03-11 Fix sorting of direction list in test_directions function
    [test_directions.py]
2026-03-11 Enhance direction handling in test_directions function to include None values and provide warnings for missing direction data
    [test_directions.py]
2026-03-11 Remove redundant print statement for missing direction data in test_directions function
    [test_directions.py]
2026-03-11 Update STOP_ID in configuration to monitor arrivals at the correct bus stop
    [config.txt]
2026-03-11 Refactor direction handling to use headsigns instead of direction IDs in configuration and code
    [config.txt]
2026-03-11 Update configuration to include specific headsigns for display routes
    [config.txt]
2026-03-19 Added CAD files
    [Acrylic Faceplate.DWG, Acrylic Faceplate.SLDPRT, Bottom Case.SLDPRT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]
2026-03-19 Add assembly instructions and assets
    Add detailed hardware and case assembly steps to docs/Instructions.md and include supporting assets. Adds CAD/GRT Bus Time Face Decal.pdf, a wiring diagram, and three photos (AssembledCase, Component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
2026-03-19 Refactor code structure for improved readability and maintainability
    [Acrylic Faceplate.DWG, Bottom Case.STL, PCB Support Bracket.STL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]
2026-03-19 Update Leg part and add STL exports
    Modify CAD/Leg.SLDPRT (binary change) and add CAD/Leg.STL and print_files/Leg.STL. The STL files provide exported geometry for 3D printing, with a copy placed in print_files for printing workflows.
    [Leg.SLDPRT, Leg.STL]
2026-03-19 Enhance documentation and configuration for static GTFS data refresh interval; update instructions and parts list for clarity
    [config.txt]
2026-03-23 Add electrical tape to parts list and include tools required for assembly
2026-04-07 Enhance API session management by tracking consecutive failures and resetting the session after three failures; update utility knife note in parts list for clarity.
    [bus_arrival_times.py]
